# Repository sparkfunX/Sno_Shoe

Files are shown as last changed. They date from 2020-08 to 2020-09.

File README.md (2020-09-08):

# Snō Shoe

A Qwiic, USB-C and HDMI breakout board for the [Alorium Technology Snō](https://www.sparkfun.com/products/15145)

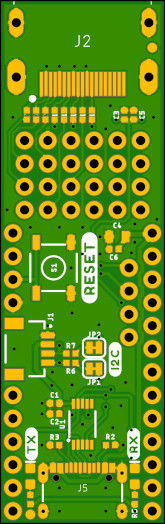
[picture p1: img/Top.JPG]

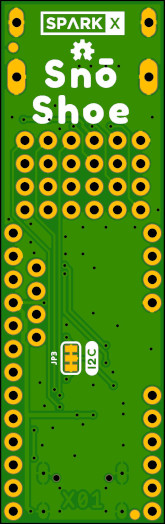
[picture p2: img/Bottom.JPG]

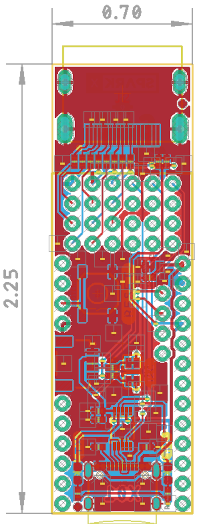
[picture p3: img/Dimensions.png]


The Alorium Technologies Snō is based on the Intel MAX 10 10M16SAU169C8G FPGA. It includes an ATmega328-compatible microcontroller core
which appears as an Arduino Uno and can be configured as normal through the Arduino IDE. It supports Serial, I<sup>2</sup>C and all the usual
Uno features.

The Snō Shoe makes it easy to connect to the Snō over:
- USB-C (instead of needing to use an FTDI adapter)
- HDMI
- Qwiic (I<sup>2</sup>C)

Paul has written an "Xcelerator Block" for the Snō which produces VGA text and graphics over HDMI. The assembled Snō Shoe is essentially an
Arduino-programmable Serial & Qwiic VGA Adapter.

- https://github.com/PaulZC/XLR8_VGA_HDMI_XB

## Repository Contents

- **/Hardware** - Eagle PCB, SCH and LBR design files
- **[LICENSE.md](./LICENSE.md)** contains the licence information

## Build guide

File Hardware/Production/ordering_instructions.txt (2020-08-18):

panel size, 142x131mm
PCB thickness, 1.6mm
number of layers, 2
soldermask color, Black
silkscreen color, White
oz copper, 1oz
finish, HASL lead free
stencils, top
pcs per panel, 14
min trace width, 0.2032mm / 0.0080in
min drill size, 0.3000mm / 0.0118in

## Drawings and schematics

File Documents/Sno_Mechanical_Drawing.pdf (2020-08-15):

# Mechanical Drawing

1.7”

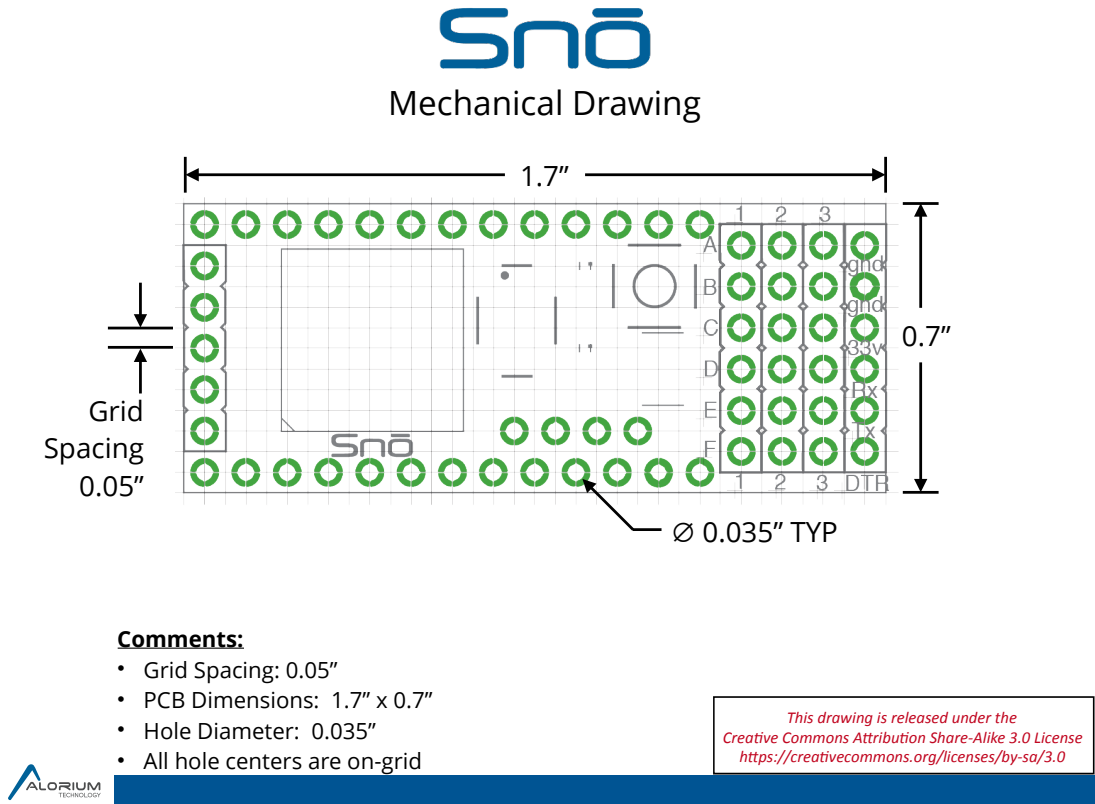
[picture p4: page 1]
Grid Spacing 0.05”; ∅ 0.035” TYP

Comments:
• Grid Spacing: 0.05”
• PCB Dimensions: 1.7” x 0.7”
• Hole Diameter: 0.035”
• All hole centers are on-grid

This drawing is released under the

Crea1ve Commons A6ribu1on Share-Alike 3.0 License
h6ps://crea1vecommons.org/licenses/by-sa/3.0

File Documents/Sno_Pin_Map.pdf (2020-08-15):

# Snō Development Board

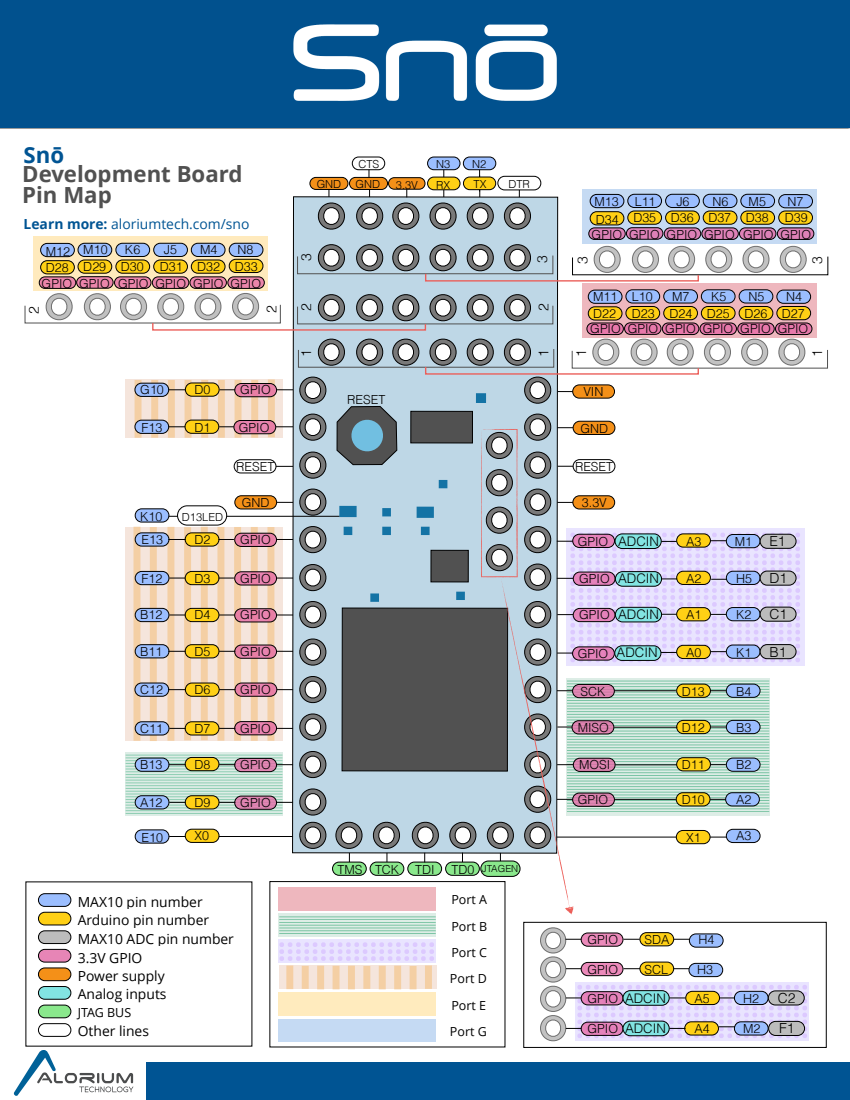
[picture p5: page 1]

GPIO GPIO GPIO

Learn more: aloriumtech.com/sno

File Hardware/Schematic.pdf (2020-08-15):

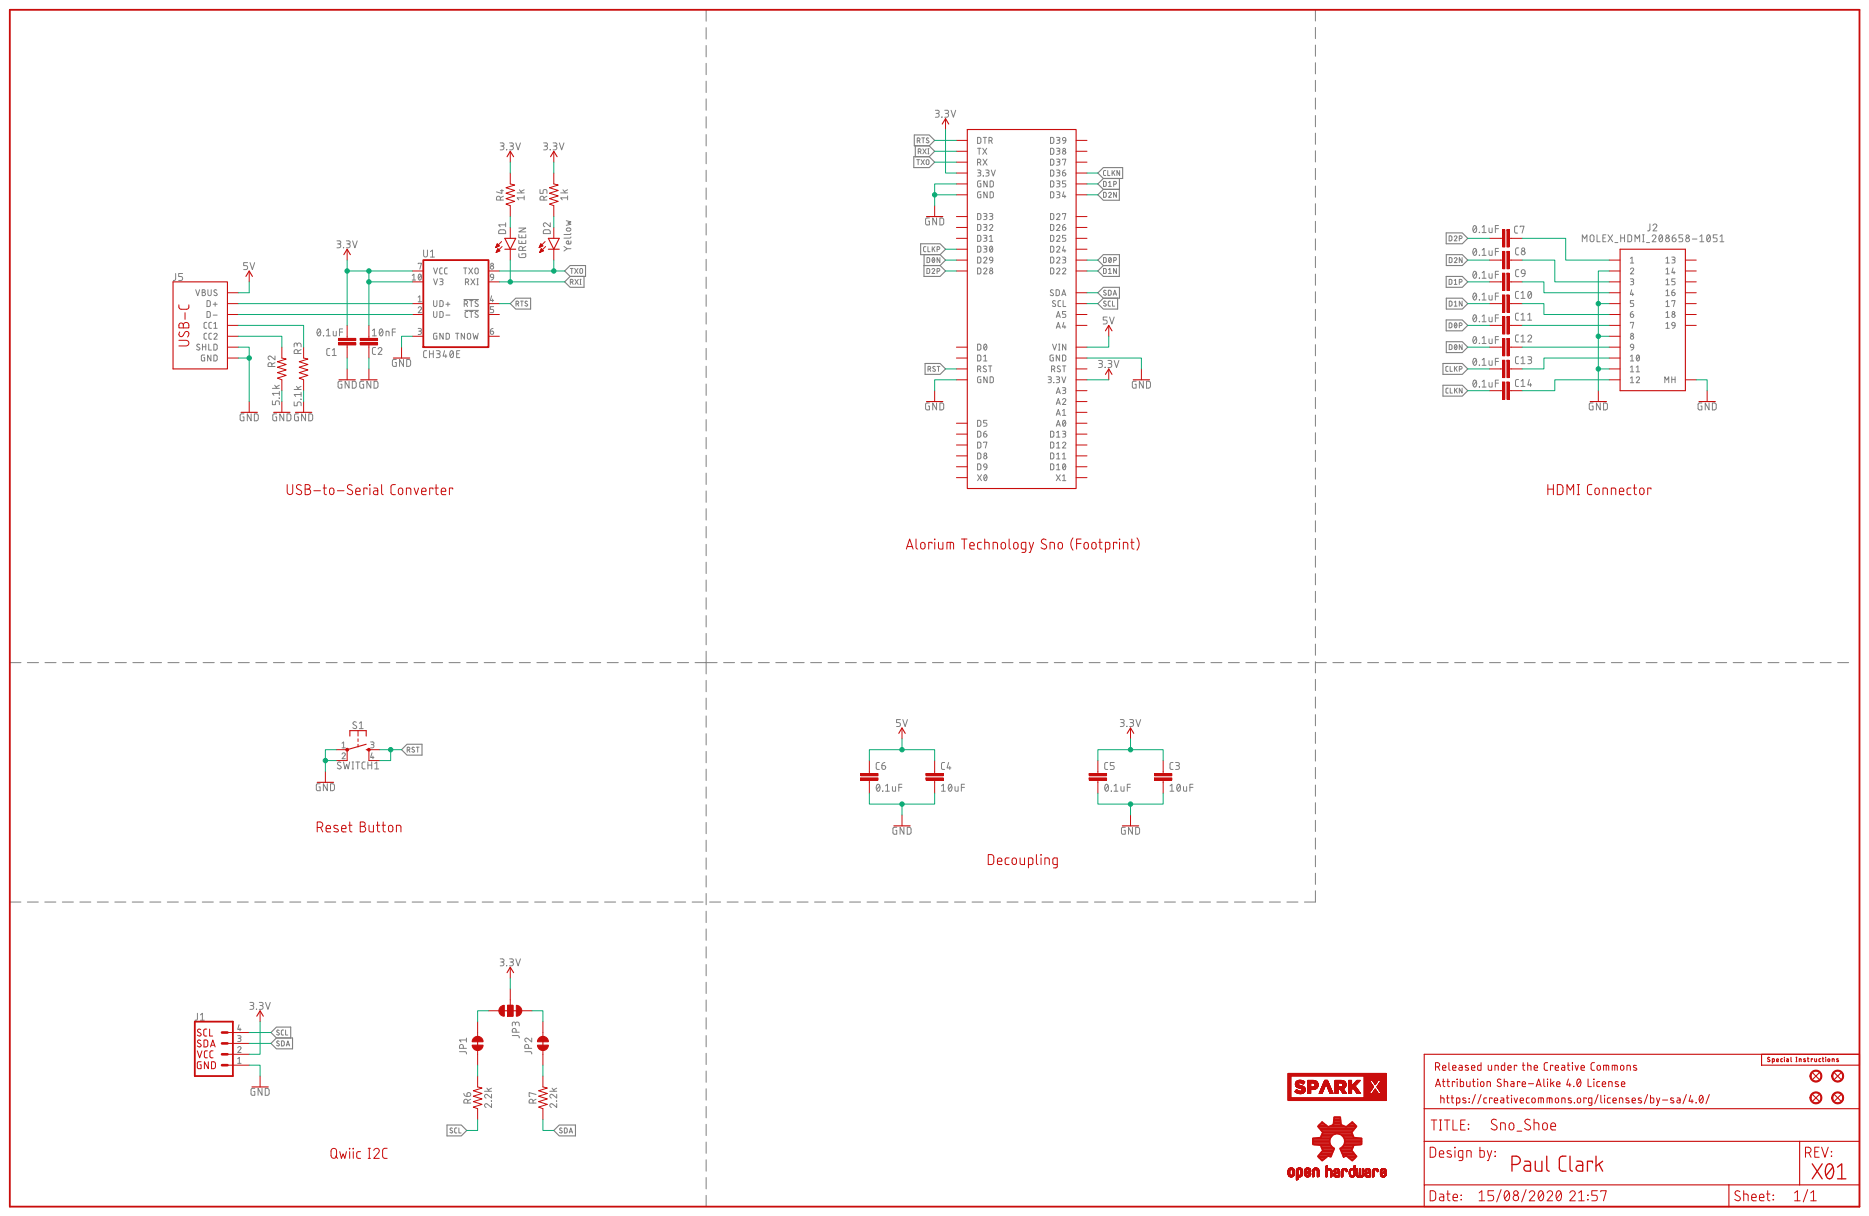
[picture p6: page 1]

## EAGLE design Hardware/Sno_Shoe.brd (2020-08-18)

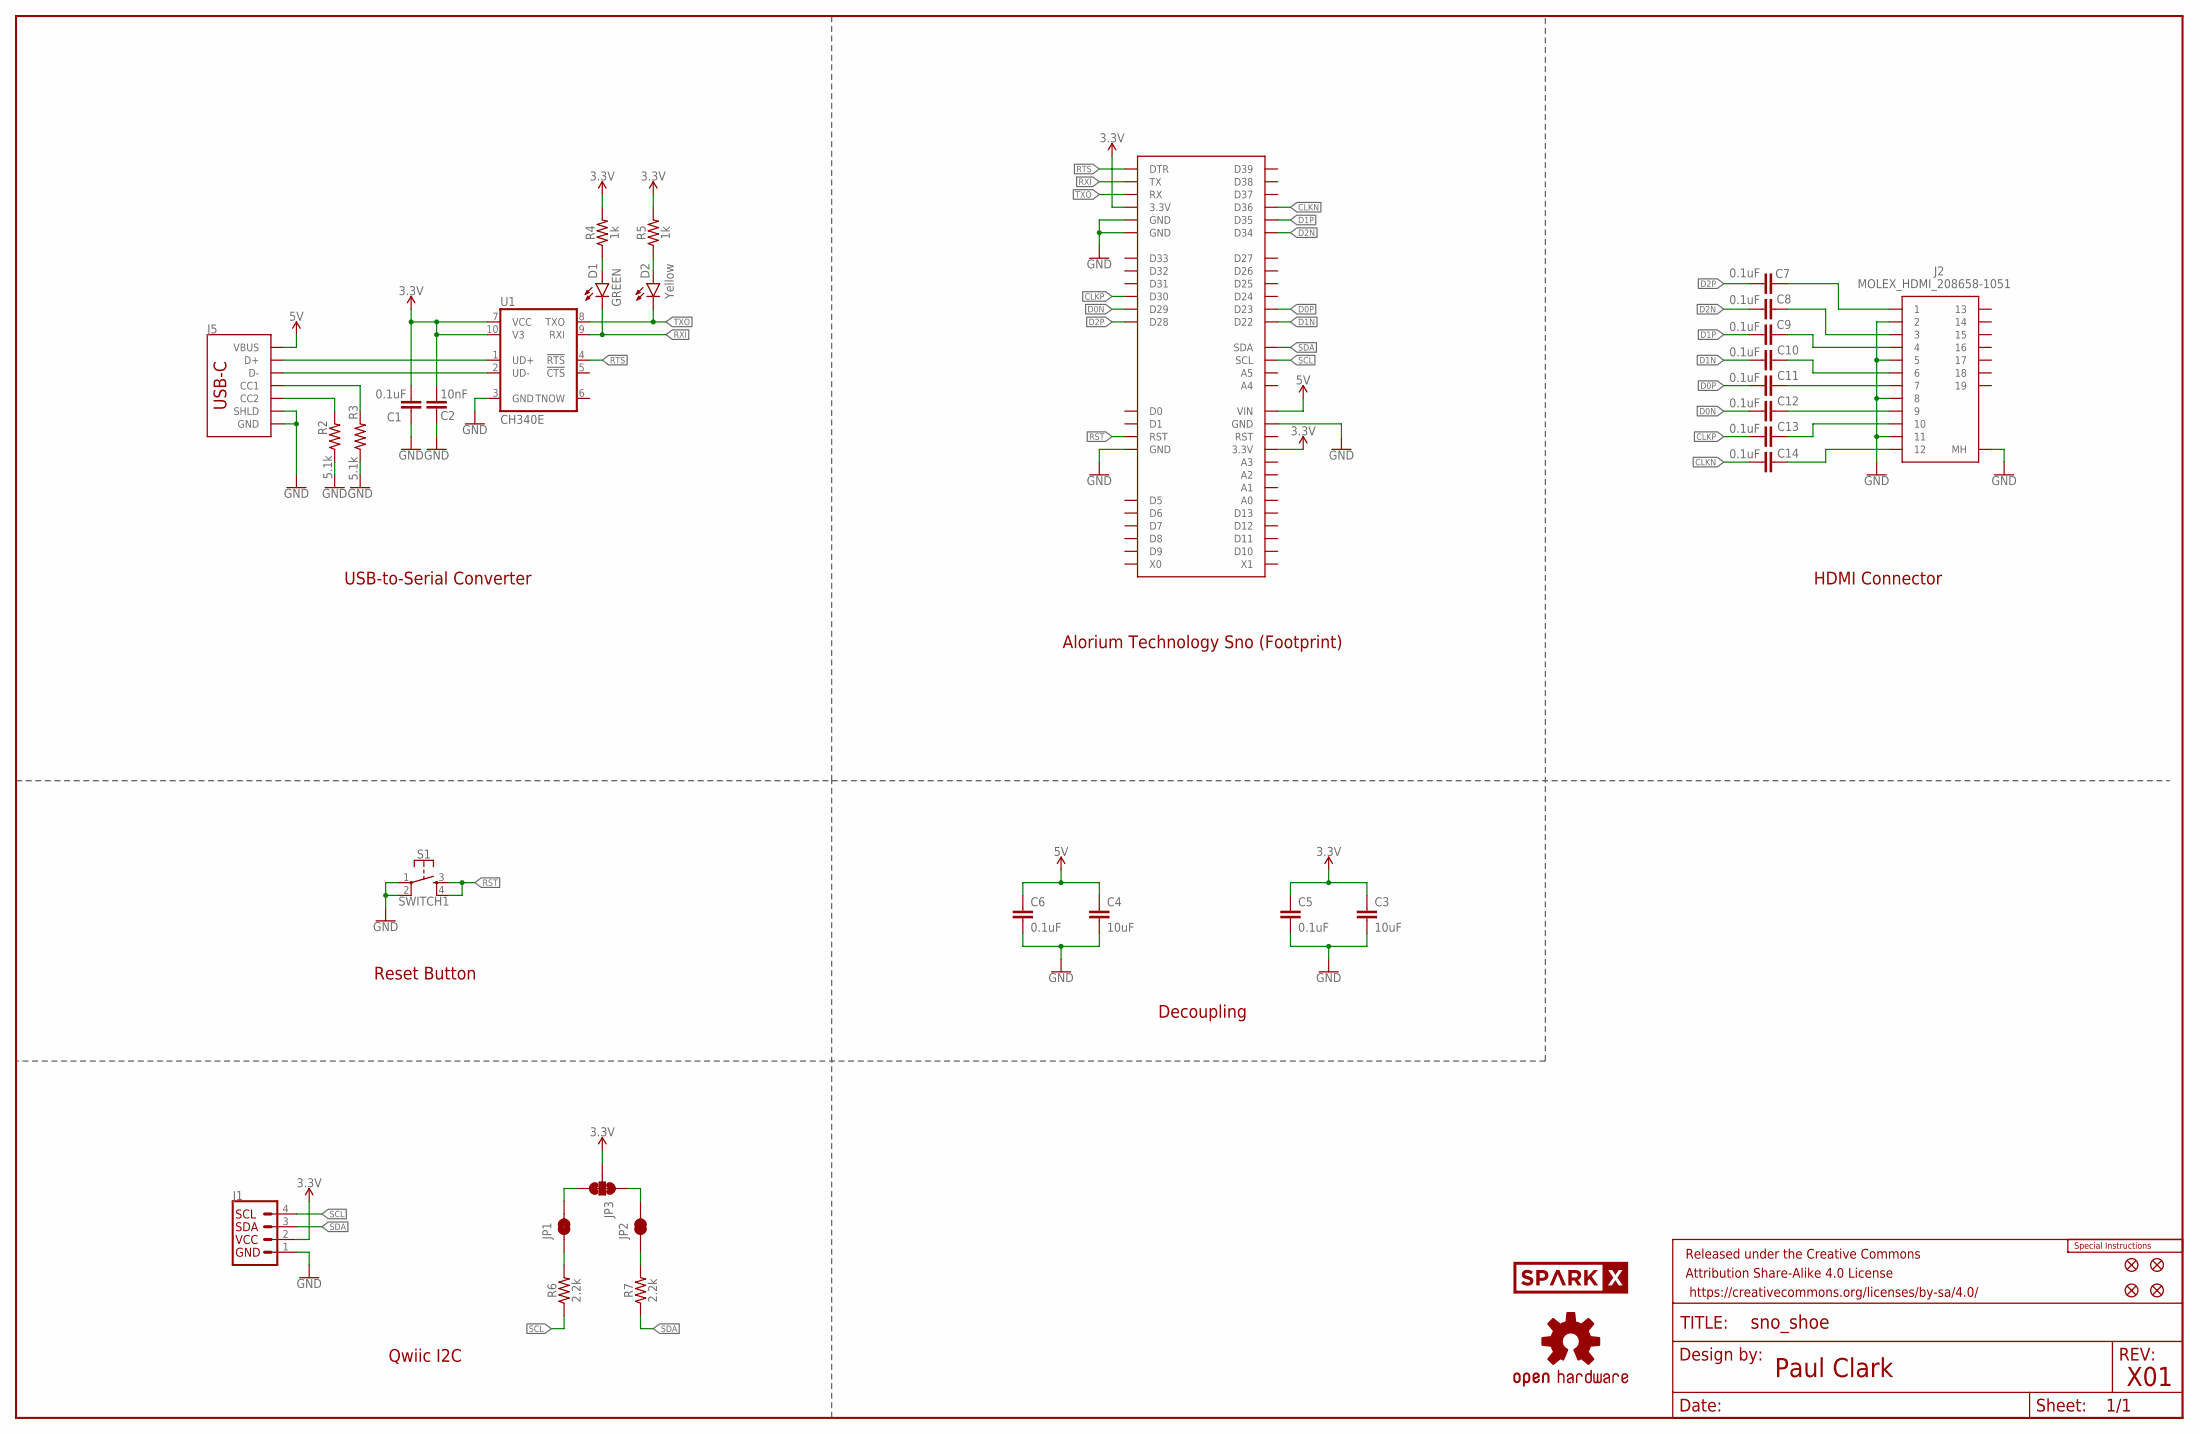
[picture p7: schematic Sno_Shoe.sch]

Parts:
C1, C5, C6, C7, C8, C9, C10, C11, C12, C13, C14: 0.1uF; 0402-TIGHT
C2: 10nF; 0402-TIGHT
C3: 10uF; 0402-TIGHT
C4: 10uF; 0805
D1: GREEN; LED-0603
D2: Yellow; LED-0603
FD1, FD2, FD3, FD4: FIDUCIAL1X2; FIDUCIAL-1X2
FRAME1: FRAME-LEDGER; CREATIVE_COMMONS
J1: QWIIC_RIGHT_ANGLE; JST04_1MM_RA
J2: MOLEX_HDMI_208658-1051
J5: USB_C_4-LAYER_PADS; USB-C-16P_4LAYER-PADS
JP1, JP2: JUMPER-SMT_2_NC_TRACE_SILK; SMT-JUMPER_2_NC_TRACE_SILK
JP3: JUMPER-SMT_3_2-NC_TRACE_SILK; SMT-JUMPER_3_2-NC_TRACE_SILK
LOGO1: SPECIAL_INSTRUCTIONS-ORDERING; ORDERING_INSTRUCTIONS
LOGO2: OSHW-LOGOMINI; OSHW-LOGO-MINI
R2, R3: 5.1k; 0402-TIGHT
R4, R5: 1k; 0402-TIGHT
R6, R7: 2.2k; 0402-TIGHT
S1: SWITCH1; TACTILE_SWITCH_SMD_5.2MM
SPARKX2: SPARKX-LOGO4; SPARKX-MEDIUM
U1: CH340E; MSOP10
U$1: SNO_MISSING_PINS

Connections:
3.3V: C1.1, C2.1, C3.1, C5.1, J1.2, JP3.2, R4.2, R5.2, U1.7 (VCC), U1.10 (V3), U$1.P$28 (3.3V), U$1.P$56 (3.3V)
5V: C4.1, C6.1, J5.VBUS1 (VBUS), J5.VBUS2 (VBUS), U$1.P$31 (VIN)
CC3: J5.B5 (CC2), R2.2
CC4: J5.A5 (CC1), R3.2
CLKN: C14.1, U$1.P$50 (D36)
CLKP: C13.1, U$1.P$44 (D30)
D0N: C12.1, U$1.P$43 (D29)
D0P: C11.1, U$1.P$37 (D23)
D1N: C10.1, U$1.P$36 (D22)
D1P: C9.1, U$1.P$49 (D35)
D2N: C8.1, U$1.P$48 (D34)
D2P: C7.1, U$1.P$42 (D28)
D+2: J5.A6 (D+), J5.B6 (D+), U1.1 (UD+)
D-2: J5.A7 (D-), J5.B7 (D-), U1.2 (UD-)
GND: C1.2, C2.2, C3.2, C4.2, C5.2, C6.2, J1.1, J2.2, J2.5, J2.8, J2.11, J2.MH1 (MH), J2.MH2 (MH), J2.MH3 (MH), J2.MH4 (MH), J5.GND, J5.GND2 (GND), J5.SHLD1 (SHLD), J5.SHLD2 (SHLD), J5.SHLD3 (SHLD), J5.SHLD4 (SHLD), R2.1, R3.1, S1.1, S1.2, U1.3 (GND), U$1.P$4 (GND), U$1.P$30 (GND), U$1.P$54 (GND), U$1.P$55 (GND)
unnamed: JP2.2, JP3.1
unnamed: JP1.2, JP3.3
unnamed: JP1.1, R6.2
unnamed: JP2.1, R7.2
unnamed: C7.2, J2.1
unnamed: C8.2, J2.3
unnamed: C9.2, J2.4
unnamed: C10.2, J2.6
unnamed: C11.2, J2.7
unnamed: C12.2, J2.9
unnamed: C13.2, J2.10
unnamed: C14.2, J2.12
unnamed: D1.A, R4.1
unnamed: D2.A, R5.1
RST: S1.3, S1.4, U$1.P$3 (RST)
RTS: U1.4 (!RTS), U$1.P$59 (DTR)
RXI: D1.C, U1.9 (RXI), U$1.P$58 (TX)
SCL: J1.4, R6.1, U$1.P$34 (SCL)
SDA: J1.3, R7.1, U$1.P$35 (SDA)
TXO: D2.C, U1.8 (TXO), U$1.P$57 (RX)

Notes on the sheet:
USB-to-Serial Converter
Alorium Technology Sno (Footprint)
HDMI Connector
Reset Button
Qwiic I2C
Decoupling
Paul Clark
X01

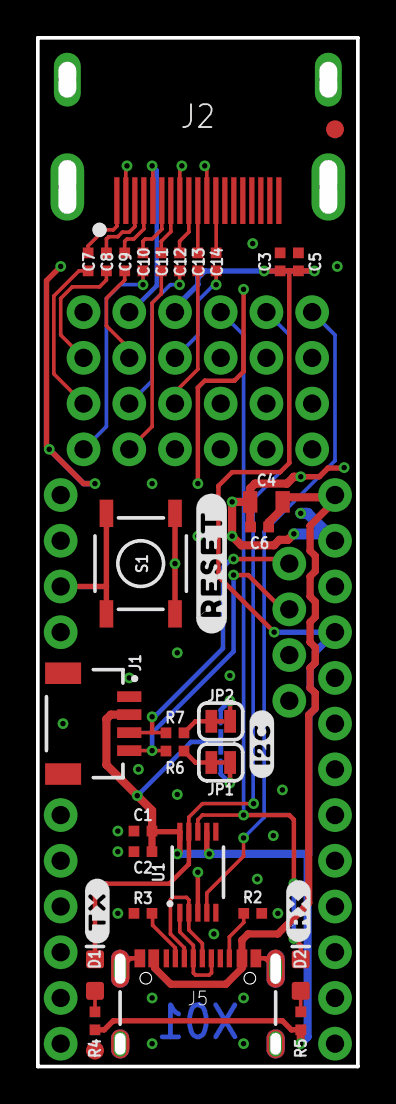
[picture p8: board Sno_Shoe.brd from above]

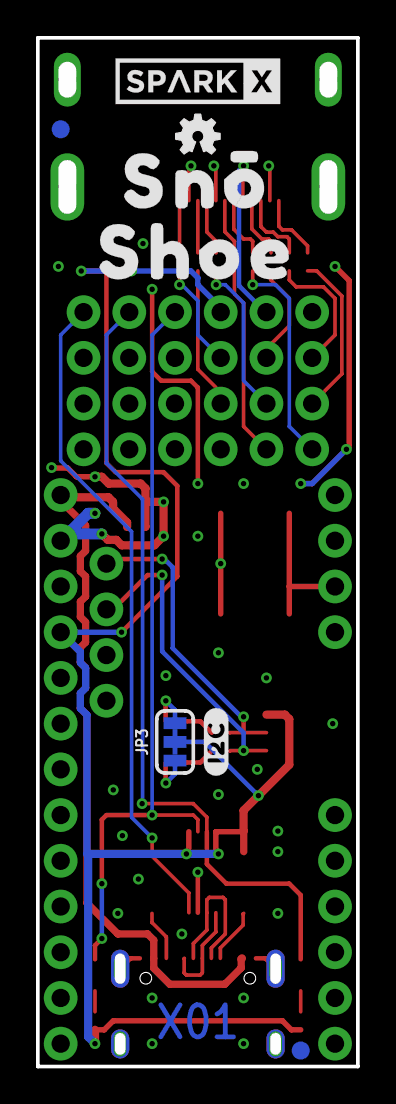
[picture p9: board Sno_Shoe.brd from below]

Board: 2 copper layers, 17.8 x 57.1 mm, 47 parts (9 on the bottom side), 35 nets.

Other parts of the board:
U$2: SNO0
U$3: SHOE0
U$4: #0
U$5: #RESET#0
U$6, U$7: #I2C#0
U$8: #TX#0
U$9: #RX#0

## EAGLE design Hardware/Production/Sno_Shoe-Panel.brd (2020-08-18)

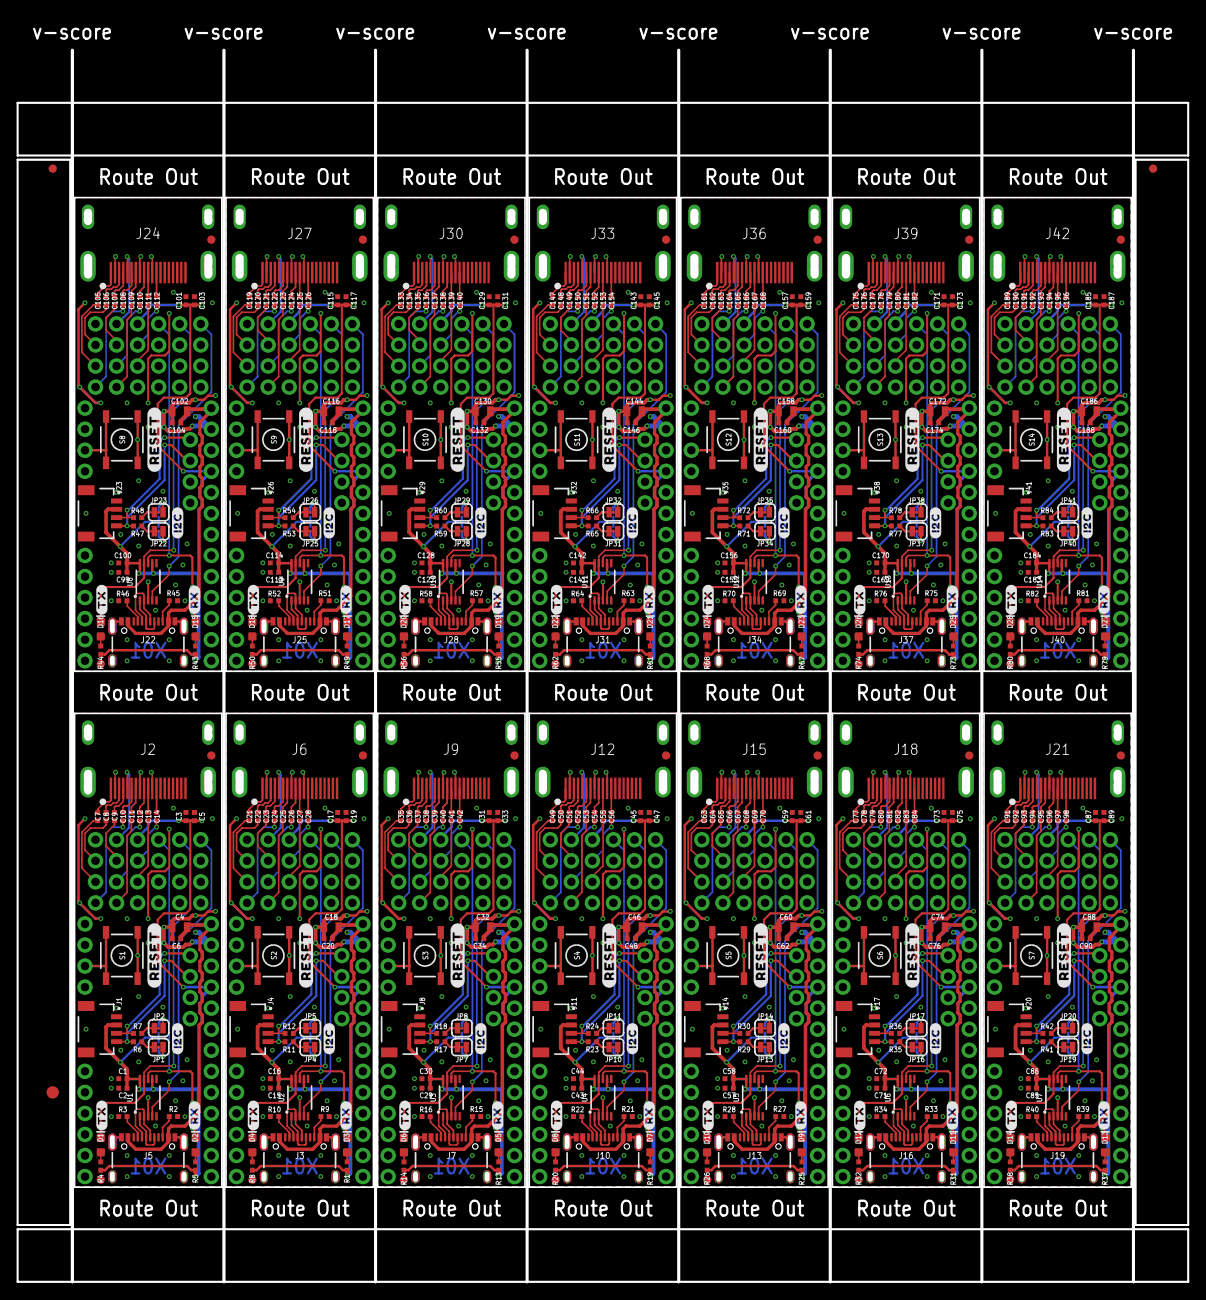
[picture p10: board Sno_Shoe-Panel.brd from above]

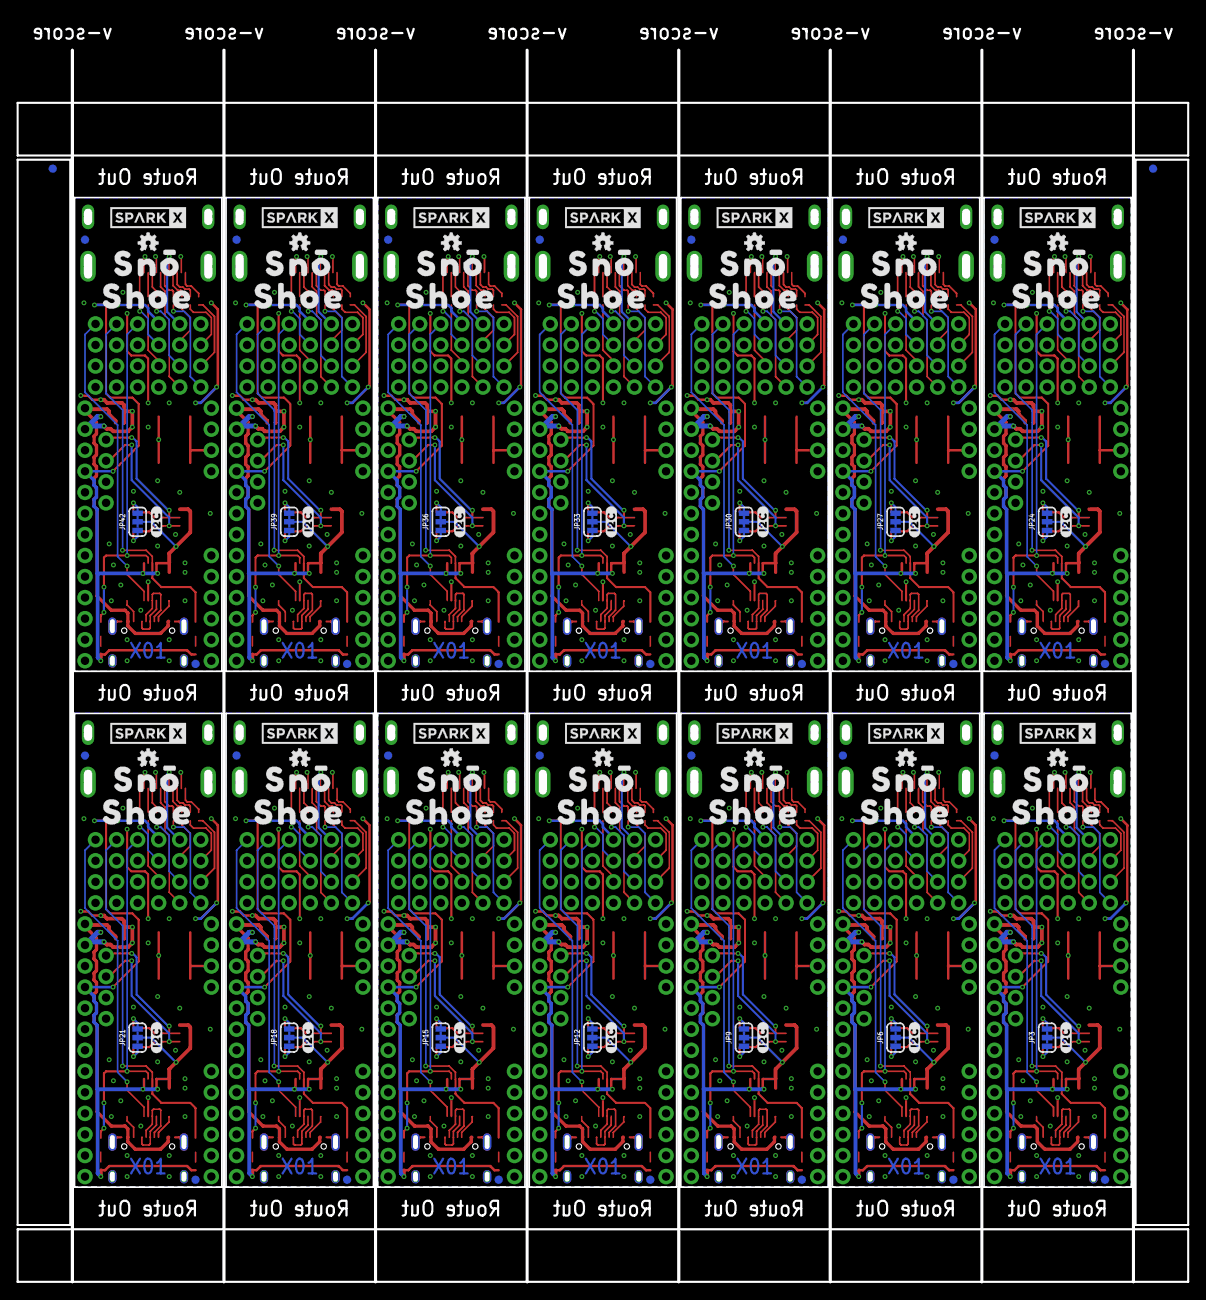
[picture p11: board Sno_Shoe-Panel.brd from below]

Board: 2 copper layers, 141.2 x 148.6 mm, 635 parts (128 on the bottom side), 490 nets.

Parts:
C1, C5, C6, C7, C8, C9, C10, C11, C12, C13, C14, C16, C19, C20, C21, C22, C23, C24, C25, C26, C27, C28, C30, C33, C34, C35, C36, C37, C38, C39, C40, C41, C42, C44, C47, C48, C49, C50, C51, C52, C53, C54, C55, C56, C58, C61, C62, C63, C64, C65, C66, C67, C68, C69, C70, C72, C75, C76, C77, C78, C79, C80, C81, C82, C83, C84, C86, C89, C90, C91, C92, C93, C94, C95, C96, C97, C98, C100, C103, C104, C105, C106, C107, C108, C109, C110, C111, C112, C114, C117, C118, C119, C120, C121, C122, C123, C124, C125, C126, C128, C131, C132, C133, C134, C135, C136, C137, C138, C139, C140, C142, C145, C146, C147, C148, C149, C150, C151, C152, C153, C154, C156, C159, C160, C161, C162, C163, C164, C165, C166, C167, C168, C170, C173, C174, C175, C176, C177, C178, C179, C180, C181, C182, C184, C187, C188, C189, C190, C191, C192, C193, C194, C195, C196: 0.1uF; 0402-TIGHT
C2, C15, C29, C43, C57, C71, C85, C99, C113, C127, C141, C155, C169, C183: 10nF; 0402-TIGHT
C3, C17, C31, C45, C59, C73, C87, C101, C115, C129, C143, C157, C171, C185: 10uF; 0402-TIGHT
C4, C18, C32, C46, C60, C74, C88, C102, C116, C130, C144, C158, C172, C186: 10uF; 0805
D1, D4, D6, D8, D10, D12, D14, D16, D18, D20, D22, D24, D26, D28: GREEN; LED-0603
D2, D3, D5, D7, D9, D11, D13, D15, D17, D19, D21, D23, D25, D27: Yellow; LED-0603
E$1, E$2, E$3, E$4: FIDUCIAL-1X2
E$5: FIDUCIAL-1.5X3
FD1, FD2, FD3, FD4, FD5, FD6, FD7, FD8, FD9, FD10, FD11, FD12, FD13, FD14, FD15, FD16, FD17, FD18, FD19, FD20, FD21, FD22, FD23, FD24, FD25, FD26, FD27, FD28, FD29, FD30, FD31, FD32, FD33, FD34, FD35, FD36, FD37, FD38, FD39, FD40, FD41, FD42, FD43, FD44, FD45, FD46, FD47, FD48, FD49, FD50, FD51, FD52, FD53, FD54, FD55, FD56: FIDUCIAL1X2; FIDUCIAL-1X2
J1, J4, J8, J11, J14, J17, J20, J23, J26, J29, J32, J35, J38, J41: QWIIC_RIGHT_ANGLE; JST04_1MM_RA
J2, J6, J9, J12, J15, J18, J21, J24, J27, J30, J33, J36, J39, J42: MOLEX_HDMI_208658-1051
J3, J5, J7, J10, J13, J16, J19, J22, J25, J28, J31, J34, J37, J40: USB-C-16P_4LAYER-PADS
JP1, JP2, JP4, JP5, JP7, JP8, JP10, JP11, JP13, JP14, JP16, JP17, JP19, JP20, JP22, JP23, JP25, JP26, JP28, JP29, JP31, JP32, JP34, JP35, JP37, JP38, JP40, JP41: JUMPER-SMT_2_NC_TRACE_SILK; SMT-JUMPER_2_NC_TRACE_SILK
JP3, JP6, JP9, JP12, JP15, JP18, JP21, JP24, JP27, JP30, JP33, JP36, JP39, JP42: JUMPER-SMT_3_2-NC_TRACE_SILK; SMT-JUMPER_3_2-NC_TRACE_SILK
LOGO1, LOGO2, LOGO3, LOGO4, LOGO5, LOGO6, LOGO7, LOGO8, LOGO9, LOGO10, LOGO11, LOGO12, LOGO13, LOGO14: OSHW-LOGOMINI; OSHW-LOGO-MINI
R1, R4, R5, R8, R13, R14, R19, R20, R25, R26, R31, R32, R37, R38, R43, R44, R49, R50, R55, R56, R61, R62, R67, R68, R73, R74, R79, R80: 1k; 0402-TIGHT
R2, R3, R9, R10, R15, R16, R21, R22, R27, R28, R33, R34, R39, R40, R45, R46, R51, R52, R57, R58, R63, R64, R69, R70, R75, R76, R81, R82: 5.1k; 0402-TIGHT
R6, R7, R11, R12, R17, R18, R23, R24, R29, R30, R35, R36, R41, R42, R47, R48, R53, R54, R59, R60, R65, R66, R71, R72, R77, R78, R83, R84: 2.2k; 0402-TIGHT
S1, S2, S3, S4, S5, S6, S7, S8, S9, S10, S11, S12, S13, S14: SWITCH1; TACTILE_SWITCH_SMD_5.2MM
SPARKX1, SPARKX2, SPARKX3, SPARKX4, SPARKX5, SPARKX6, SPARKX7, SPARKX8, SPARKX9, SPARKX10, SPARKX11, SPARKX12, SPARKX13, SPARKX14: SPARKX-LOGO4; SPARKX-MEDIUM
U1, U2, U3, U4, U5, U6, U7, U8, U9, U10, U11, U12, U13, U14: CH340E; MSOP10
U$1, U$10, U$19, U$28, U$37, U$46, U$55, U$64, U$73, U$82, U$91, U$100, U$109, U$118: SNO_MISSING_PINS
U$2, U$11, U$20, U$29, U$38, U$47, U$56, U$65, U$74, U$83, U$92, U$101, U$110, U$119: SNO0
U$3, U$12, U$21, U$30, U$39, U$48, U$57, U$66, U$75, U$84, U$93, U$102, U$111, U$120: SHOE0
U$4, U$13, U$22, U$31, U$40, U$49, U$58, U$67, U$76, U$85, U$94, U$103, U$112, U$121: #0
U$5, U$14, U$23, U$32, U$41, U$50, U$59, U$68, U$77, U$86, U$95, U$104, U$113, U$122: #RESET#0
U$6, U$7, U$15, U$16, U$24, U$25, U$33, U$34, U$42, U$43, U$51, U$52, U$60, U$61, U$69, U$70, U$78, U$79, U$87, U$88, U$96, U$97, U$105, U$106, U$114, U$115, U$123, U$124: #I2C#0
U$8, U$17, U$26, U$35, U$44, U$53, U$62, U$71, U$80, U$89, U$98, U$107, U$116, U$125: #TX#0
U$9, U$18, U$27, U$36, U$45, U$54, U$63, U$72, U$81, U$90, U$99, U$108, U$117, U$126: #RX#0

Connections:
3.3V: C1.1, C2.1, C3.1, C5.1, J1.2, JP3.2, R4.2, R5.2, U1.7, U1.10, U$1.P$28, U$1.P$56
3.3V1: C15.1, C16.1, C17.1, C19.1, J4.2, JP6.2, R1.2, R8.2, U2.7, U2.10, U$10.P$28, U$10.P$56
3.3V2: C29.1, C30.1, C31.1, C33.1, J8.2, JP9.2, R13.2, R14.2, U3.7, U3.10, U$19.P$28, U$19.P$56
3.3V3: C43.1, C44.1, C45.1, C47.1, J11.2, JP12.2, R19.2, R20.2, U4.7, U4.10, U$28.P$28, U$28.P$56
3.3V4: C57.1, C58.1, C59.1, C61.1, J14.2, JP15.2, R25.2, R26.2, U5.7, U5.10, U$37.P$28, U$37.P$56
3.3V5: C71.1, C72.1, C73.1, C75.1, J17.2, JP18.2, R31.2, R32.2, U6.7, U6.10, U$46.P$28, U$46.P$56
3.3V6: C85.1, C86.1, C87.1, C89.1, J20.2, JP21.2, R37.2, R38.2, U7.7, U7.10, U$55.P$28, U$55.P$56
3.3V7: C99.1, C100.1, C101.1, C103.1, J23.2, JP24.2, R43.2, R44.2, U8.7, U8.10, U$64.P$28, U$64.P$56
3.3V8: C113.1, C114.1, C115.1, C117.1, J26.2, JP27.2, R49.2, R50.2, U9.7, U9.10, U$73.P$28, U$73.P$56
3.3V9: C127.1, C128.1, C129.1, C131.1, J29.2, JP30.2, R55.2, R56.2, U10.7, U10.10, U$82.P$28, U$82.P$56
3.3V10: C141.1, C142.1, C143.1, C145.1, J32.2, JP33.2, R61.2, R62.2, U11.7, U11.10, U$91.P$28, U$91.P$56
3.3V11: C155.1, C156.1, C157.1, C159.1, J35.2, JP36.2, R67.2, R68.2, U12.7, U12.10, U$100.P$28, U$100.P$56
3.3V12: C169.1, C170.1, C171.1, C173.1, J38.2, JP39.2, R73.2, R74.2, U13.7, U13.10, U$109.P$28, U$109.P$56
3.3V13: C183.1, C184.1, C185.1, C187.1, J41.2, JP42.2, R79.2, R80.2, U14.7, U14.10, U$118.P$28, U$118.P$56
5V: C4.1, C6.1, J5.VBUS1, J5.VBUS2, U$1.P$31
5V1: C18.1, C20.1, J3.VBUS1, J3.VBUS2, U$10.P$31
5V2: C32.1, C34.1, J7.VBUS1, J7.VBUS2, U$19.P$31
5V3: C46.1, C48.1, J10.VBUS1, J10.VBUS2, U$28.P$31
5V4: C60.1, C62.1, J13.VBUS1, J13.VBUS2, U$37.P$31
5V5: C74.1, C76.1, J16.VBUS1, J16.VBUS2, U$46.P$31
5V6: C88.1, C90.1, J19.VBUS1, J19.VBUS2, U$55.P$31
5V7: C102.1, C104.1, J22.VBUS1, J22.VBUS2, U$64.P$31
5V8: C116.1, C118.1, J25.VBUS1, J25.VBUS2, U$73.P$31
5V9: C130.1, C132.1, J28.VBUS1, J28.VBUS2, U$82.P$31
5V10: C144.1, C146.1, J31.VBUS1, J31.VBUS2, U$91.P$31
5V11: C158.1, C160.1, J34.VBUS1, J34.VBUS2, U$100.P$31
5V12: C172.1, C174.1, J37.VBUS1, J37.VBUS2, U$109.P$31
5V13: C186.1, C188.1, J40.VBUS1, J40.VBUS2, U$118.P$31
CC1: J3.B5, R9.2
CC2: J3.A5, R10.2
CC3: J5.B5, R2.2
CC4: J5.A5, R3.2
CC5: J7.B5, R15.2
CC6: J7.A5, R16.2
CC7: J10.B5, R21.2
CC8: J10.A5, R22.2
CC9: J13.B5, R27.2
CC10: J13.A5, R28.2
CC11: J16.B5, R33.2
CC12: J16.A5, R34.2
CC13: J19.B5, R39.2
CC14: J19.A5, R40.2
CC15: J22.B5, R45.2
CC16: J22.A5, R46.2
CC17: J25.B5, R51.2
CC18: J25.A5, R52.2
CC19: J28.B5, R57.2
CC20: J28.A5, R58.2
CC21: J31.B5, R63.2
CC22: J31.A5, R64.2
CC23: J34.B5, R69.2
CC24: J34.A5, R70.2
CC25: J37.B5, R75.2
CC26: J37.A5, R76.2
CC27: J40.B5, R81.2
CC28: J40.A5, R82.2
CLKN: C14.1, U$1.P$50
CLKN1: C28.1, U$10.P$50
CLKN2: C42.1, U$19.P$50
CLKN3: C56.1, U$28.P$50
CLKN4: C70.1, U$37.P$50
CLKN5: C84.1, U$46.P$50
CLKN6: C98.1, U$55.P$50
CLKN7: C112.1, U$64.P$50
CLKN8: C126.1, U$73.P$50
CLKN9: C140.1, U$82.P$50
CLKN10: C154.1, U$91.P$50
CLKN11: C168.1, U$100.P$50
CLKN12: C182.1, U$109.P$50
CLKN13: C196.1, U$118.P$50
CLKP: C13.1, U$1.P$44
CLKP1: C27.1, U$10.P$44
CLKP2: C41.1, U$19.P$44
CLKP3: C55.1, U$28.P$44
CLKP4: C69.1, U$37.P$44
CLKP5: C83.1, U$46.P$44
CLKP6: C97.1, U$55.P$44
CLKP7: C111.1, U$64.P$44
CLKP8: C125.1, U$73.P$44
CLKP9: C139.1, U$82.P$44
CLKP10: C153.1, U$91.P$44
CLKP11: C167.1, U$100.P$44
CLKP12: C181.1, U$109.P$44
CLKP13: C195.1, U$118.P$44
D0N: C12.1, U$1.P$43
D0N1: C26.1, U$10.P$43
D0N2: C40.1, U$19.P$43
D0N3: C54.1, U$28.P$43
D0N4: C68.1, U$37.P$43
D0N5: C82.1, U$46.P$43
D0N6: C96.1, U$55.P$43
D0N7: C110.1, U$64.P$43
D0N8: C124.1, U$73.P$43
D0N9: C138.1, U$82.P$43
D0N10: C152.1, U$91.P$43
D0N11: C166.1, U$100.P$43
D0N12: C180.1, U$109.P$43
D0N13: C194.1, U$118.P$43
D0P: C11.1, U$1.P$37
D0P1: C25.1, U$10.P$37
D0P2: C39.1, U$19.P$37
D0P3: C53.1, U$28.P$37
D0P4: C67.1, U$37.P$37
D0P5: C81.1, U$46.P$37
D0P6: C95.1, U$55.P$37
D0P7: C109.1, U$64.P$37
D0P8: C123.1, U$73.P$37
D0P9: C137.1, U$82.P$37
D0P10: C151.1, U$91.P$37
D0P11: C165.1, U$100.P$37
D0P12: C179.1, U$109.P$37
D0P13: C193.1, U$118.P$37
D1N: C10.1, U$1.P$36
D1N1: C24.1, U$10.P$36
D1N2: C38.1, U$19.P$36
D1N3: C52.1, U$28.P$36
D1N4: C66.1, U$37.P$36
D1N5: C80.1, U$46.P$36
D1N6: C94.1, U$55.P$36
D1N7: C108.1, U$64.P$36
D1N8: C122.1, U$73.P$36
D1N9: C136.1, U$82.P$36
D1N10: C150.1, U$91.P$36
D1N11: C164.1, U$100.P$36
D1N12: C178.1, U$109.P$36
D1N13: C192.1, U$118.P$36
D1P: C9.1, U$1.P$49
D1P1: C23.1, U$10.P$49
D1P2: C37.1, U$19.P$49
D1P3: C51.1, U$28.P$49
D1P4: C65.1, U$37.P$49
D1P5: C79.1, U$46.P$49
D1P6: C93.1, U$55.P$49
D1P7: C107.1, U$64.P$49
D1P8: C121.1, U$73.P$49
D1P9: C135.1, U$82.P$49
D1P10: C149.1, U$91.P$49
D1P11: C163.1, U$100.P$49
D1P12: C177.1, U$109.P$49
D1P13: C191.1, U$118.P$49
D2N: C8.1, U$1.P$48
D2N1: C22.1, U$10.P$48
D2N2: C36.1, U$19.P$48
D2N3: C50.1, U$28.P$48
D2N4: C64.1, U$37.P$48
D2N5: C78.1, U$46.P$48
D2N6: C92.1, U$55.P$48
D2N7: C106.1, U$64.P$48
D2N8: C120.1, U$73.P$48
D2N9: C134.1, U$82.P$48
D2N10: C148.1, U$91.P$48
D2N11: C162.1, U$100.P$48
D2N12: C176.1, U$109.P$48
D2N13: C190.1, U$118.P$48
D2P: C7.1, U$1.P$42
D2P1: C21.1, U$10.P$42
D2P2: C35.1, U$19.P$42
D2P3: C49.1, U$28.P$42
D2P4: C63.1, U$37.P$42
D2P5: C77.1, U$46.P$42
D2P6: C91.1, U$55.P$42
D2P7: C105.1, U$64.P$42
D2P8: C119.1, U$73.P$42
D2P9: C133.1, U$82.P$42
D2P10: C147.1, U$91.P$42
D2P11: C161.1, U$100.P$42
D2P12: C175.1, U$109.P$42
D2P13: C189.1, U$118.P$42
D+1: J3.A6, J3.B6, U2.1
D+2: J5.A6, J5.B6, U1.1
D+3: J7.A6, J7.B6, U3.1
D+4: J10.A6, J10.B6, U4.1
D+5: J13.A6, J13.B6, U5.1
D+6: J16.A6, J16.B6, U6.1
D+7: J19.A6, J19.B6, U7.1
D+8: J22.A6, J22.B6, U8.1
D+9: J25.A6, J25.B6, U9.1
D+10: J28.A6, J28.B6, U10.1
D+11: J31.A6, J31.B6, U11.1
D+12: J34.A6, J34.B6, U12.1
D+13: J37.A6, J37.B6, U13.1
D+14: J40.A6, J40.B6, U14.1
D-1: J3.A7, J3.B7, U2.2
D-2: J5.A7, J5.B7, U1.2
D-3: J7.A7, J7.B7, U3.2
D-4: J10.A7, J10.B7, U4.2
D-5: J13.A7, J13.B7, U5.2
D-6: J16.A7, J16.B7, U6.2
D-7: J19.A7, J19.B7, U7.2
D-8: J22.A7, J22.B7, U8.2
D-9: J25.A7, J25.B7, U9.2
D-10: J28.A7, J28.B7, U10.2
D-11: J31.A7, J31.B7, U11.2
D-12: J34.A7, J34.B7, U12.2
D-13: J37.A7, J37.B7, U13.2
D-14: J40.A7, J40.B7, U14.2
GND: C1.2, C2.2, C3.2, C4.2, C5.2, C6.2, J1.1, J2.2, J2.5, J2.8, J2.11, J2.MH1, J2.MH2, J2.MH3, J2.MH4, J5.GND, J5.GND2, J5.SHLD1, J5.SHLD2, J5.SHLD3, J5.SHLD4, R2.1, R3.1, S1.1, S1.2, U1.3, U$1.P$4, U$1.P$30, U$1.P$54, U$1.P$55
GND1: C15.2, C16.2, C17.2, C18.2, C19.2, C20.2, J3.GND, J3.GND2, J3.SHLD1, J3.SHLD2, J3.SHLD3, J3.SHLD4, J4.1, J6.2, J6.5, J6.8, J6.11, J6.MH1, J6.MH2, J6.MH3, J6.MH4, R9.1, R10.1, S2.1, S2.2, U2.3, U$10.P$4, U$10.P$30, U$10.P$54, U$10.P$55
GND2: C29.2, C30.2, C31.2, C32.2, C33.2, C34.2, J7.GND, J7.GND2, J7.SHLD1, J7.SHLD2, J7.SHLD3, J7.SHLD4, J8.1, J9.2, J9.5, J9.8, J9.11, J9.MH1, J9.MH2, J9.MH3, J9.MH4, R15.1, R16.1, S3.1, S3.2, U3.3, U$19.P$4, U$19.P$30, U$19.P$54, U$19.P$55
GND3: C43.2, C44.2, C45.2, C46.2, C47.2, C48.2, J10.GND, J10.GND2, J10.SHLD1, J10.SHLD2, J10.SHLD3, J10.SHLD4, J11.1, J12.2, J12.5, J12.8, J12.11, J12.MH1, J12.MH2, J12.MH3, J12.MH4, R21.1, R22.1, S4.1, S4.2, U4.3, U$28.P$4, U$28.P$30, U$28.P$54, U$28.P$55
GND4: C57.2, C58.2, C59.2, C60.2, C61.2, C62.2, J13.GND, J13.GND2, J13.SHLD1, J13.SHLD2, J13.SHLD3, J13.SHLD4, J14.1, J15.2, J15.5, J15.8, J15.11, J15.MH1, J15.MH2, J15.MH3, J15.MH4, R27.1, R28.1, S5.1, S5.2, U5.3, U$37.P$4, U$37.P$30, U$37.P$54, U$37.P$55
GND5: C71.2, C72.2, C73.2, C74.2, C75.2, C76.2, J16.GND, J16.GND2, J16.SHLD1, J16.SHLD2, J16.SHLD3, J16.SHLD4, J17.1, J18.2, J18.5, J18.8, J18.11, J18.MH1, J18.MH2, J18.MH3, J18.MH4, R33.1, R34.1, S6.1, S6.2, U6.3, U$46.P$4, U$46.P$30, U$46.P$54, U$46.P$55
GND6: C85.2, C86.2, C87.2, C88.2, C89.2, C90.2, J19.GND, J19.GND2, J19.SHLD1, J19.SHLD2, J19.SHLD3, J19.SHLD4, J20.1, J21.2, J21.5, J21.8, J21.11, J21.MH1, J21.MH2, J21.MH3, J21.MH4, R39.1, R40.1, S7.1, S7.2, U7.3, U$55.P$4, U$55.P$30, U$55.P$54, U$55.P$55
GND7: C99.2, C100.2, C101.2, C102.2, C103.2, C104.2, J22.GND, J22.GND2, J22.SHLD1, J22.SHLD2, J22.SHLD3, J22.SHLD4, J23.1, J24.2, J24.5, J24.8, J24.11, J24.MH1, J24.MH2, J24.MH3, J24.MH4, R45.1, R46.1, S8.1, S8.2, U8.3, U$64.P$4, U$64.P$30, U$64.P$54, U$64.P$55
GND8: C113.2, C114.2, C115.2, C116.2, C117.2, C118.2, J25.GND, J25.GND2, J25.SHLD1, J25.SHLD2, J25.SHLD3, J25.SHLD4, J26.1, J27.2, J27.5, J27.8, J27.11, J27.MH1, J27.MH2, J27.MH3, J27.MH4, R51.1, R52.1, S9.1, S9.2, U9.3, U$73.P$4, U$73.P$30, U$73.P$54, U$73.P$55
GND9: C127.2, C128.2, C129.2, C130.2, C131.2, C132.2, J28.GND, J28.GND2, J28.SHLD1, J28.SHLD2, J28.SHLD3, J28.SHLD4, J29.1, J30.2, J30.5, J30.8, J30.11, J30.MH1, J30.MH2, J30.MH3, J30.MH4, R57.1, R58.1, S10.1, S10.2, U10.3, U$82.P$4, U$82.P$30, U$82.P$54, U$82.P$55
GND10: C141.2, C142.2, C143.2, C144.2, C145.2, C146.2, J31.GND, J31.GND2, J31.SHLD1, J31.SHLD2, J31.SHLD3, J31.SHLD4, J32.1, J33.2, J33.5, J33.8, J33.11, J33.MH1, J33.MH2, J33.MH3, J33.MH4, R63.1, R64.1, S11.1, S11.2, U11.3, U$91.P$4, U$91.P$30, U$91.P$54, U$91.P$55
GND11: C155.2, C156.2, C157.2, C158.2, C159.2, C160.2, J34.GND, J34.GND2, J34.SHLD1, J34.SHLD2, J34.SHLD3, J34.SHLD4, J35.1, J36.2, J36.5, J36.8, J36.11, J36.MH1, J36.MH2, J36.MH3, J36.MH4, R69.1, R70.1, S12.1, S12.2, U12.3, U$100.P$4, U$100.P$30, U$100.P$54, U$100.P$55
GND12: C169.2, C170.2, C171.2, C172.2, C173.2, C174.2, J37.GND, J37.GND2, J37.SHLD1, J37.SHLD2, J37.SHLD3, J37.SHLD4, J38.1, J39.2, J39.5, J39.8, J39.11, J39.MH1, J39.MH2, J39.MH3, J39.MH4, R75.1, R76.1, S13.1, S13.2, U13.3, U$109.P$4, U$109.P$30, U$109.P$54, U$109.P$55
GND13: C183.2, C184.2, C185.2, C186.2, C187.2, C188.2, J40.GND, J40.GND2, J40.SHLD1, J40.SHLD2, J40.SHLD3, J40.SHLD4, J41.1, J42.2, J42.5, J42.8, J42.11, J42.MH1, J42.MH2, J42.MH3, J42.MH4, R81.1, R82.1, S14.1, S14.2, U14.3, U$118.P$4, U$118.P$30, U$118.P$54, U$118.P$55
unnamed: D4.A, R8.1
unnamed: JP2.2, JP3.1
unnamed: JP1.2, JP3.3
unnamed: JP1.1, R6.2
unnamed: JP2.1, R7.2
unnamed: C7.2, J2.1
unnamed: C8.2, J2.3
unnamed: C9.2, J2.4
unnamed: C10.2, J2.6
unnamed: C11.2, J2.7
unnamed: C12.2, J2.9
unnamed: C13.2, J2.10
unnamed: C14.2, J2.12
unnamed: D3.A, R1.1
unnamed: JP5.2, JP6.1
unnamed: JP4.2, JP6.3
unnamed: JP4.1, R11.2
unnamed: JP5.1, R12.2
unnamed: C21.2, J6.1
unnamed: C22.2, J6.3
unnamed: C23.2, J6.4
unnamed: C24.2, J6.6
unnamed: C25.2, J6.7
unnamed: C26.2, J6.9
unnamed: C27.2, J6.10
unnamed: D1.A, R4.1
unnamed: D2.A, R5.1
unnamed: C28.2, J6.12
unnamed: D6.A, R14.1
unnamed: D5.A, R13.1
unnamed: JP8.2, JP9.1
unnamed: JP7.2, JP9.3
unnamed: JP7.1, R17.2
unnamed: JP8.1, R18.2
unnamed: C35.2, J9.1
unnamed: C36.2, J9.3
unnamed: C37.2, J9.4
unnamed: C38.2, J9.6
unnamed: C39.2, J9.7
unnamed: C40.2, J9.9
unnamed: C41.2, J9.10
unnamed: C42.2, J9.12
unnamed: D8.A, R20.1
unnamed: D7.A, R19.1
unnamed: JP11.2, JP12.1
unnamed: JP10.2, JP12.3
unnamed: JP10.1, R23.2
unnamed: JP11.1, R24.2
unnamed: C49.2, J12.1
unnamed: C50.2, J12.3
unnamed: C51.2, J12.4
unnamed: C52.2, J12.6
unnamed: C53.2, J12.7
unnamed: C54.2, J12.9
unnamed: C55.2, J12.10
unnamed: C56.2, J12.12
unnamed: D10.A, R26.1
unnamed: D9.A, R25.1
unnamed: JP14.2, JP15.1
unnamed: JP13.2, JP15.3
unnamed: JP13.1, R29.2
unnamed: JP14.1, R30.2
unnamed: C63.2, J15.1
unnamed: C64.2, J15.3
unnamed: C65.2, J15.4
unnamed: C66.2, J15.6
unnamed: C67.2, J15.7
unnamed: C68.2, J15.9
unnamed: C69.2, J15.10
unnamed: C70.2, J15.12
unnamed: D12.A, R32.1
unnamed: D11.A, R31.1
unnamed: JP17.2, JP18.1
unnamed: JP16.2, JP18.3
unnamed: JP16.1, R35.2
unnamed: JP17.1, R36.2
unnamed: C77.2, J18.1
unnamed: C78.2, J18.3
unnamed: C79.2, J18.4
unnamed: C80.2, J18.6
unnamed: C81.2, J18.7
unnamed: C82.2, J18.9
unnamed: C83.2, J18.10
unnamed: C84.2, J18.12
unnamed: D14.A, R38.1
unnamed: D13.A, R37.1
unnamed: JP20.2, JP21.1
unnamed: JP19.2, JP21.3
unnamed: JP19.1, R41.2
unnamed: JP20.1, R42.2
unnamed: C91.2, J21.1
unnamed: C92.2, J21.3
unnamed: C93.2, J21.4
unnamed: C94.2, J21.6
unnamed: C95.2, J21.7
unnamed: C96.2, J21.9
unnamed: C97.2, J21.10
unnamed: C98.2, J21.12
unnamed: D16.A, R44.1
unnamed: D15.A, R43.1
unnamed: JP23.2, JP24.1
unnamed: JP22.2, JP24.3
unnamed: JP22.1, R47.2
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

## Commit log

2020-08-15 Changed the HDMI connector footprint
    [Sno_Shoe.brd, Sno_Shoe.sch]
2020-08-18 Added the production panel
    [Sno_Shoe-Panel.GBL, Sno_Shoe-Panel.GBO, Sno_Shoe-Panel.GBP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]

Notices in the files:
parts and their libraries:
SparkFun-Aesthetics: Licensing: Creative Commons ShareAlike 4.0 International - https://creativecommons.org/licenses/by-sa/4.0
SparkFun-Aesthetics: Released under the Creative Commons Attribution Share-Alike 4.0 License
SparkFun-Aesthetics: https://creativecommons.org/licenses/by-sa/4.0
